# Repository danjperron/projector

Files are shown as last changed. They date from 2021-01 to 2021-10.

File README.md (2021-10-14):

# projector
8mm to mp4 using Raspberry Pi

video Explanation
https://www.youtube.com/watch?v=7BlS7_QZtZ0

** update Oct.2021<br>
projectorV2.py is a updated version (speed up version).
The streaming is close in capture mode!
The stepper move just after the image capture.
Image manipulation is done when the film move. 

** update jan.2020<br>
add film Length<br>
add skip dark frame (my camera made a blank frame every time it starts)

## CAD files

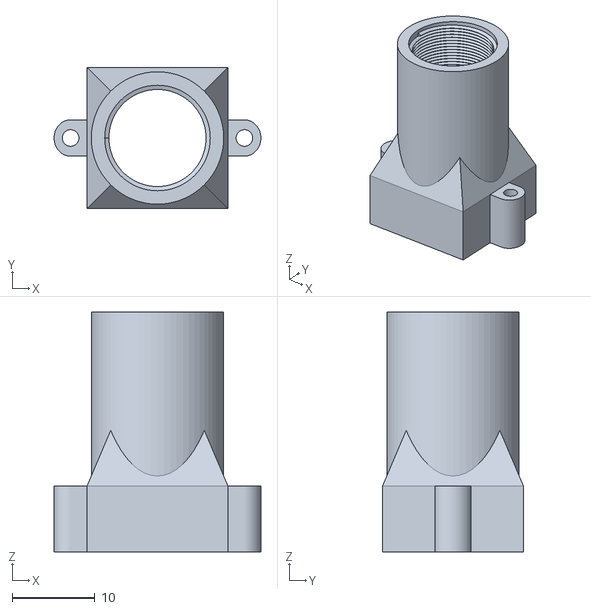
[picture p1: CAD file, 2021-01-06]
camera base M12 lens extender.stl
25.0 x 17.0 x 29.0

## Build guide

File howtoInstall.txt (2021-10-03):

sudo apt update
sudo apt upgrade

from arduino.cc download the latest version of arduino arm 32 bits
-  Be sure it is the arm 32 bits version
- untar and install arduino 
- tar -xf ./Downloads/ardui....xz
- cd arduin..
- sudo ./install.sh

git clone https://github.com/danjperron/projector.git

- start arduino
- open pi/projector/arduino/projector.ino
- save it to is own folder project
- select arduino uno
- on line 6 & 7 you need to install two libraries
- Start the browser on the pi and open url
- https://github.com/adafruit/Adafruit-Motor-Shield-library
- select code, download zip
- now open the browser to the other library,
- https://github.com/adafruit/AccelStepper
- select code, download zip
- close browser
- from arduino gui goto  sketch, add library
- from the Downloads folder add the two libraries one after the other
- now compile and upload,
- port should be set for arduino on nmine is /dev/ttyACM0

****** now the projector

- set configuration for the raspberry Pi

sudo raspi-config

- enable pi camera
- change password
- change hostname
- reboot

--- now is time to install needed library
--- I need to install some python library using sudo even if isn't recommended
sudo python3 -m pip install --upgrade --force-reinstall pip
sudo apt install python3-opencv
pip3 install imutils
sudo pip3 install imutils
sudo pip3 install pillow
sudo apt install python3-tk
sudo apt install python3-pil python3-pil.imagetk
sudo pip3 install picamera
sudo mkdir /mnt/video
sudo chmod ugo+r+w /mnt/video
cd /mnt/video

***** now the projector should work without sudo
cd
cd projector
python3 projector.py

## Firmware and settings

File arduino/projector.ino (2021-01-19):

// MultiStepper
// -*- mode: C++ -*-
//
// Control both Stepper motors at the same time with different speeds
// and accelerations. 
// Requires the AFMotor library (https://github.com/adafruit/Adafruit-Motor-Shield-library)
// And AccelStepper with AFMotor support (https://github.com/adafruit/AccelStepper)
// Public domain!

#include <AccelStepper.h>
#include <AFMotor.h>


#define TARGET_STEP 210
#define MIN_STEP_CHECK  150
#define POST_STEP   205



int cposition;
int lightFlag=0;
int motorFlag=0;
int frameCount=0;
int nextFlag=0;

// two stepper motors one on each port
AF_Stepper motor1(200, 1);
AF_DCMotor motor2(3,MOTOR12_1KHZ);
//AF_Stepper motor2(200, 2);

// you can change these to DOUBLE or INTERLEAVE or MICROSTEP!
// wrappers for the first motor!
void forwardstep1() {  
  motor1.onestep(FORWARD, SINGLE);
}
void backwardstep1() {  
  motor1.onestep(BACKWARD, SINGLE);
}


// Motor shield has two motor ports, now we'll wrap them in an AccelStepper object
AccelStepper stepper1(forwardstep1, backwardstep1);


//  status return from serial communication
//  Light  tab  motor  tab  Frame_count  tab Stepper_position  return
void sendStatus()
{
  Serial.print(lightFlag,DEC);
  Serial.print("\t");
  Serial.print(motorFlag,DEC);
  Serial.print("\t");
  Serial.print(frameCount,DEC);
  Serial.print("\t");
  Serial.println(cposition,DEC);
  Serial.flush();
}



unsigned long Counter;
void setup()
{  
  Serial.begin(9600);
  Serial.flush();
  pinMode(A2,INPUT);
  motor2.setSpeed(255);
  LightOff();
  stepper1.setMaxSpeed(400.0);
  stepper1.setAcceleration(400.0);
}





void stopMotor()
{
                  stepper1.setCurrentPosition(0);
                  stepper1.moveTo(0);
                  motor1.release();
                  motorFlag=0;
                  cposition=0;
}

void LightOff()
{
  motor2.run(FORWARD);
  lightFlag=0;
}

void LightOn()
{
  motor2.run(BACKWARD);
  lightFlag=1;
} 


// this is the command received throught the serial port
//
//  0 -> light OFF
//  1 -> light ON
//  C -> stop and reset position
//  I -> request status
//  N -> Next picture frame
//  S -> stop
// system doesnt care about cariage return or line feed


void loop()
{

  byte new_v;
  
 
  
  if(Serial.available()>0) {
    int inByte = Serial.read();
    
    switch (toupper(inByte)) {
      
      case '0': LightOff();
                sendStatus();
                break;
                 
      case '1': LightOn();
                sendStatus();
                break;

      case 'C': stopMotor();
                frameCount=0;
                sendStatus();
                break;

      case 'I': sendStatus();
                break;
      
      case 'N': nextFlag=1;
                stepper1.setCurrentPosition(0);
                motorFlag=1;
                stepper1.moveTo(TARGET_STEP);
                sendStatus();
                break;
                 
      case 'S': stopMotor();
                sendStatus();
                break;
    }
  }
  
    new_v= digitalRead(A2);
    cposition= stepper1.currentPosition();
     if(cposition==TARGET_STEP)
       if(nextFlag)
       {
         nextFlag=0;
         motorFlag=0;
         motor1.release();
         frameCount++;
       }
     if(cposition>MIN_STEP_CHECK)
        if(new_v ==0)  
        {
          //if(cposition <POST_STEP)
           {
             stepper1.setCurrentPosition(POST_STEP);
           } 
        }


         
    stepper1.run();
}

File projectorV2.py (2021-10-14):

#!/usr/bin/python3
import tkinter as tk
import tkinter.font as tkFont
import time
import os
import ctypes
from PIL import Image
from PIL import ImageTk
import threading
import imutils
import numpy as np
from enum import Enum
from optionMenu import optionMenu
from language import Language
from arduino import Arduino
import copy
import cv2

debugFlag = False
cameraEnable = True

try:
    import picamera
    import picamera.array
except OSError:
    cameraEnable = False


'''
Copyright <2020> <Daniel Perron>

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
THE SOFTWARE IS PROVIDED "AS IS", WITHOUT WARRANTY OF ANY KIND,
EXPRESS OR IMPLIED, INCLUDING BUT NOT LIMITED TO THE WARRANTIES
OF MERCHANTABILITY, FITNESS FOR A PARTICULAR PURPOSE AND
NONINFRINGEMENT. IN NO EVENT SHALL THE AUTHORS OR COPYRIGHT
HOLDERS BE LIABLE FOR ANY CLAIM, DAMAGES OR OTHER LIABILITY,
WHETHER IN AN ACTION OF CONTRACT, TORT OR OTHERWISE, ARISING FROM,
OUT OF OR IN CONNECTION WITH THE SOFTWARE OR THE USE OR
OTHER DEALINGS IN THE SOFTWARE
'''

# PiCamera Resolution
# V1
PiCam_V1 = (2592, 1944)

# V2
PiCam_V2 = (3280, 2464)

# HQ
PiCam_HQ = (4056, 3040)
PiCam_HQ_BINNING = (2028, 1520)
# Autofind
PiCam_auto = (0, 0)

# need to rotate 180 degree
PiRotate = False
# need to flip image
PiFlip = True
logGLFlag = True


class App():

#    def __init__(self, camDevice="/dev/video0",
#                 camResolution=PiCam_HQ_BINNING,
#                 serialPort="/dev/ttyACM0"):
    def __init__(self, camDevice="/dev/video0",
                 camResolution=PiCam_auto,
                 serialPort="/dev/ttyACM0"):
        global cameraEnable
        # Language Class currently only French and English
        self.lg = Language()

        self.videoFlag = False
        self.vidOut = None
        self.logGL = None
        self.camWidth = PiCam_HQ[0]
        self.camHeight = PiCam_HQ[1]

        if cameraEnable:
            # if resolution is 0 then auto check
            try:
                if camResolution[0] == 0:
                    cam = picamera.camera.PiCamera()
                    self.camWidth = cam.MAX_RESOLUTION[0]
                    self.camHeight = cam.MAX_RESOLUTION[1]
                    cam.close()
                else:
                    self.camWidth = camResolution[0]
                    self.camHeight = camResolution[1]
            except picamera.exc.PiCameraMMALError:
                cameraEnable = False
            except picamera.exc.PiCameraError:
                cameraEnable = False

        self.camDevice = camDevice

        # output Flag
        self.saveRawImages = False
        self.saveImages = False

        # camera  settings
        self.cameraBrightness = 50
        self.cameraContrast = 0

        # frame light intensity
        self.GlValue = 0
        self.GlValuePercent = 0

        # film info
        self.film_super8 = 0
        self.film_8mm = 1
        self.filmType = self.film_super8

        self.filmRate = 18
        self.filmResolution = 720
        self.totalImages = 140000
        self.skipThreshold = 0

        # actual frame inside picture to store
        # self.viewWidth = 640
        # self.viewHeight = 480
        self.viewWidth = 1024
        self.viewHeight = 768
        self.settingConfiguration = "settings.conf"
        self.imageTop = 0
        self.imageLeft = 0
        self.imageRight = self.camWidth-1
        self.imageBottom = self.camHeight-1
        self.loadConfig()

        # default image path
        self.imagePath = "/mnt/video/images/"
        self.imagePrefix = "img_"
        self.videoPath = "/mnt/video/"
        self.videoPrefix = "video_"
        self.videoCount = 0

        # arduino object
        self.arduino = Arduino(port=serialPort)

        # turn light on
        self.arduino.light(True)
        # just to be sure
        self.arduino.light(True)

        self.root = tk.Tk()
        self.root.attributes("-fullscreen", True)
        self.root.resizable(0, 0)

        # set default language
        self.languageID = tk.IntVar(value=self.lg.languageID)
        self.root.wm_title(self.lg.getText("Title"))

        # ask thread to capture one image
        self.requestImage = False
        self.storedImage = None
        self.camThread = None

        #  CAPTURE RUN FLAG
        self.captureFlag = False
        self.piCam       = None


        # image frame
        self.imageFrame = tk.Frame(self.root,
                                   width=self.viewWidth,
                                   height=self.viewHeight,
                                   bg='black')
        self.imageFrame.pack_propagate(0)
        self.imageFrame.pack(side=tk.LEFT,
                             ipadx=0,
                             ipady=0,
                             fill="both")
        self.imagePanel = None

        # cam streaming thread
        self.stopEvent = threading.Event()
        self.camThread = threading.Thread(target=self.videoLoop, args=())
        self.camThread.start()

        # create right panel
        self.rightPanel = tk.Frame(self.root)
        self.rightPanel.pack(side=tk.RIGHT, fill="both", anchor="e")

        # create top info
        self.topInfo = tk.Frame(self.rightPanel)
        self.topInfo.pack(side=tk.TOP)

        # my photo count widget
        self.myWidgetPhotoCount(self.topInfo)
        # my capture status widget
        self.myWidgetStatus(self.topInfo)

        # create command frame
        self.commandFrame = tk.Frame(self.rightPanel)
        self.commandFrame.pack(side=tk.TOP)

        sFont = tkFont.Font(root=self.commandFrame, family="Courier", size=14)
        self.forwardButton = tk.Button(self.commandFrame,
                                       bg="gray80",
                                       command=self.OnFwdCallBack,
                                       font=sFont,
                                       width="14")
        self.forwardButton.pack(padx=2, ipady=4, pady=5)

        self.stopButton = tk.Button(self.commandFrame,
                                    command=self.OnStopCallBack,
                                    bg="red", activebackground="tomato",
                                    font=sFont,
                                    width="14")

        self.stopButton.pack(padx=2, ipady=6, pady=5)

        self.recordButton = tk.Button(self.commandFrame,
                                      command=self.OnStartCallBack,
                                      font=sFont,
                                      bg="green",
                                      activebackground="pale green",
                                      width="14")
        self.recordButton.pack(padx=2, pady=3, ipady=5)
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

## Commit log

2021-01-06 Add extender tube for M12 lense
    [camera base M12 lenses extender.stl]
2021-01-06 add extender tub
    [camera base M12 lens extender.stl]
2021-10-08 Create projectorV2.py
    Disable stream between capture frame
2021-10-14 update projectorV2
    Capture, move stepper, image manipulation and then check if stepper is done.
2021-10-14 add arduino code for stepper controller TB6600
